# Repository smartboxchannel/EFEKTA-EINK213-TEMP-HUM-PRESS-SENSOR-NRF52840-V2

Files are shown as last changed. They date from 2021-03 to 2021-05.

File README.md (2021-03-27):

# EFEKTA-EINK213-TEMP-HUM-PRESS-SENSOR-NRF52
Micro weather station. Wireless temperature, humidity, pressure, weather forecast and light sensor. Designed on the nRF52840 wireless radio module. The temperature, humidity and pressure sensor BME280, SHT20, SHT21, SI7020, SI7021, HTU20D, HTU21D is used. Light sensor MAX44009. The device is powered by a CR2450 battery. Power consumption when transmitting data is 8mA, in sleep mode is 4.7uA.

#### GDEH0213B72 (GDEH0213B73, Waveshare V2): https://ali.ski/05GbQ

(250x122,2.13inch E-Ink raw display panel Without PCB Communicate via SPI interface)

#### MS88SF3: https://ali.ski/I_UNg

(New FCC CE RoHs Certificated Compact (18.5×12.5×2mm) and Flexible ultra-low power wireless BLE 5.0 Module based on nRF52840 SoCs)

#### Don't donate to me, it doesn't work in this world: https://paypal.me/efektalab , just buy

#### Sale: https://www.tindie.com/products/diyberk/multisensor-with-an-e-ink-display-213-inch/

Video: https://youtu.be/EHj37hnhy64

More info at http://efektalab.com/eink213

---

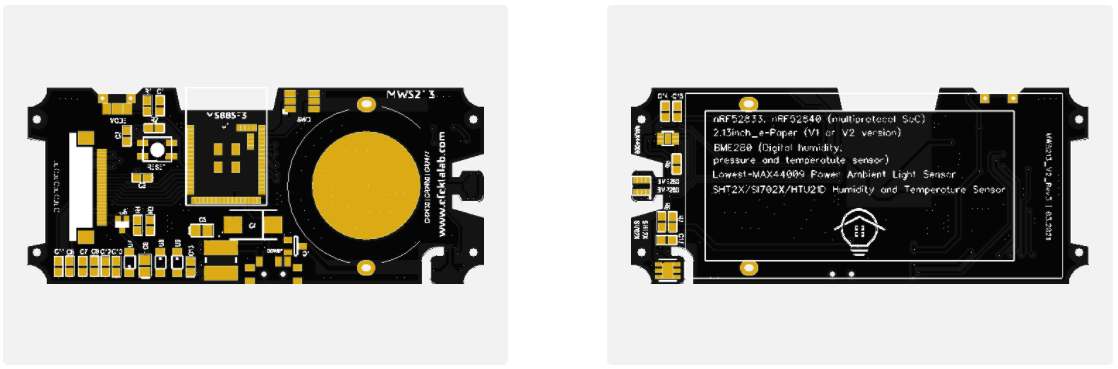
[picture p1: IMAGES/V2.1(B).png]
 

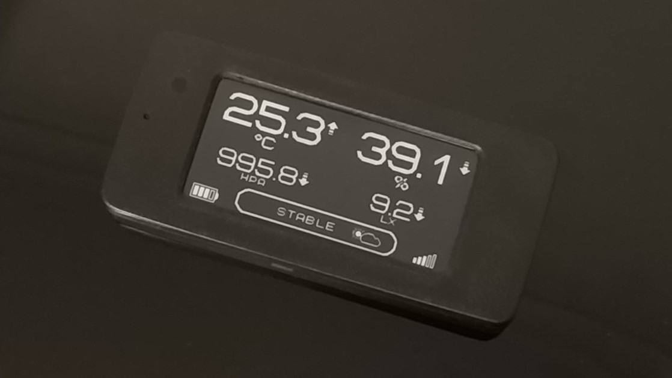
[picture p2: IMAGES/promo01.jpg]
 

---

---

### Instruction

#### First of all, I recommend installing the Arduino IDE portable (optional, but desirable)

https://www.arduino.cc/en/Guide/PortableIDE

#### 1. Install the latest arduino-nRF5 library (https://github.com/sandeepmistry/arduino-nRF5)

#### 2. Install the latest version of the MySensors library (https://github.com/mysensors/MySensors)

#### 3. Download the archive of this project to your computer

#### 4. Add support for devices of this project to the arduino-nRF5 library, the description is in the README.md file (https://github.com/smartboxchannel/EFEKTA-EINK213-TEMP-HUM-PRESS-SENSOR-NRF52840-V2/tree/master/for_sandeepmistry_nRF5/README.md)

#### 5. Add support for interrupts via gpiote, for this go to the ... packages \ sandeepmistry \ hardware \ nRF5 \ 0.7.0 \ cores \ nRF5 folder, and in the WInterrupts.c file, before the void GPIOTE_IRQHandler () function, add the line: \_\_attribute\_\_ ((weak ))

#### 6. Add the libraries in the archive () https://github.com/smartboxchannel/EFEKTA-EINK213-TEMP-HUM-PRESS-SENSOR-NRF52840-V2/tree/master/CODE/Arduino/libraries  of this project to the libraries folder on your computer ( path: ...\Documents\Arduino\libraries )

#### 7. Create an EINK213ED2 folder on your computer under the Arduino directory (Documents \ Arduino). Add the files of this project located in the Arduino section (https://github.com/smartboxchannel/EFEKTA-EINK213-TEMP-HUM-PRESS-SENSOR-NRF52840-V2/tree/master/CODE/Arduino) to the created EINK213ED2 folder

#### 8. Open the EINK213ED2.ino file in the Arduino IDE program, go to the aConfig.h tab and configure according to your board version and settings of your MySensors network.

#### 9. In the main menu of the Arduino IDE go to Tools-> Boards-> Nordic Semiconductors nRF5 Boards, in the list that opens, select the EFEKTA MWS213 V2 nRF52840 board. In the menu of the selected board, select the type of clock crystal (external), also select the Reset: Enable item.

#### 10. Click on the icon - check and then download

---

---

## Components (BOM):

MINEW MS88SF3 FCC CE RoHs Certificated wireless module nRF52840 SoCs - https://ali.ski/9LnWZ (1 pc - $7.75)

MAX44009EDT  - https://ali.ski/_PLrJ  (5 pcs - $9.3)
OR
MAX44009EDT  - https://ali.ski/bZoMnn  (1 pc - $1.9)

BME280 - https://ali.ski/wLEIir (2 pcs - $11.5)

Waveshare 250x122 2,13 - https://ali.ski/D4eOVU (1pc - $12.3)

FPC FFC 0.5mm connector socket 24 pin - https://ali.ski/lCBot0 (1 p - $0.77)

Cell Holder CR2450 - https://ali.ski/gMd2Y (10 pcs - $2)

Micro Screws M1.4 3mm - https://ali.ski/gaFdO (100 pcs - $1)

Micro Screws M1.4 5mm - https://ali.ski/gaFdO (100 pcs - $1)

Micro SMD Tact Switch 2x4 2*4*3.5 - https://ali.ski/_D78Q (10 pcs - $1)

Neodymium magnet 15x3x3m - https://ali.ski/44p3R (10 pcs - $7)

Tantalum Capacitor 100UF 10V - https://ali.ski/Lx9iQd (10 pcs - $1,85)

Inductor Power Shielded Wirewound NR5040 5x5x4mm - https://ali.ski/iblu8q (50 pcs - $3)

Micro Button Tact Switch SMD 4Pin 3X4X2.5 - https://ali.ski/sGwFu (100 pcs - $1.7)

SMD Mini Toggle Slide Switch 7-Pin On/Off - https://ali.ski/xz9Yt (100 pcs - $3.2)

SI1308EDL - https://ali.ski/Q6Y12 (20 pcs - $5.3)
OR
Si1304BDL - https://ali.ski/938Klh (100 pcs - $15.5)

SMD Chip Multilayer Ceramic Capacitor 0603 1UF 25V - https://ali.ski/p3yr60 (100 pcs - $1.5)

SMD Chip Multilayer Ceramic Capacitor 0603 0.1UF 50V - https://ali.ski/p3yr60 (100 pcs - $1.5)

SMD Chip Multilayer Ceramic Capacitor 0805 4.7UF - https://ali.ski/iFXAc (100 pcs - $1.85)

MBR0530T1G - https://ali.ski/SJM7aK (100 pcs - $1.1)

SMD LED 0805 - https://ali.ski/wb6ZP (100 pcs - $2)

1% SMD resistor 0.47R 0603 - https://ali.ski/bX9HUg (100 pcs - $1.2)

1% SMD Resistor Kit Assorted Kit 1R-1M 0603 -  https://ali.ski/npItF (660 pcs - $1.45)

SUNLU PLA Carbon Fiber Premium 3D Printer Filament - https://ali.ski/bQkNR (1 pcs - $26.5)

405nm UV Resin For 3d Printer - https://ali.ski/sW0MUm (1 pcs - $18.5)

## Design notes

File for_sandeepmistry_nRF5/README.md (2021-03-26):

#### 1. Add lines from the file boards.txt to a file with the same name(boards.txt) located in the installed 'sandeepmistry' library. 

Path: ...\AppData\Local\Arduino15\packages\sandeepmistry\hardware\nRF5\0.7.0

#### 2. Replace the file platform.txt with a similar file from this repository 

Path: ...\AppData\Local\Arduino15\packages\sandeepmistry\hardware\nRF5\0.7.0

#### 3. Add the folder EFEKTA_MWS213_V2 with all the attached files to the \0.7.0 folder

Path: ...\AppData\Local\Arduino15\packages\sandeepmistry\hardware\nRF5\0.7.0\

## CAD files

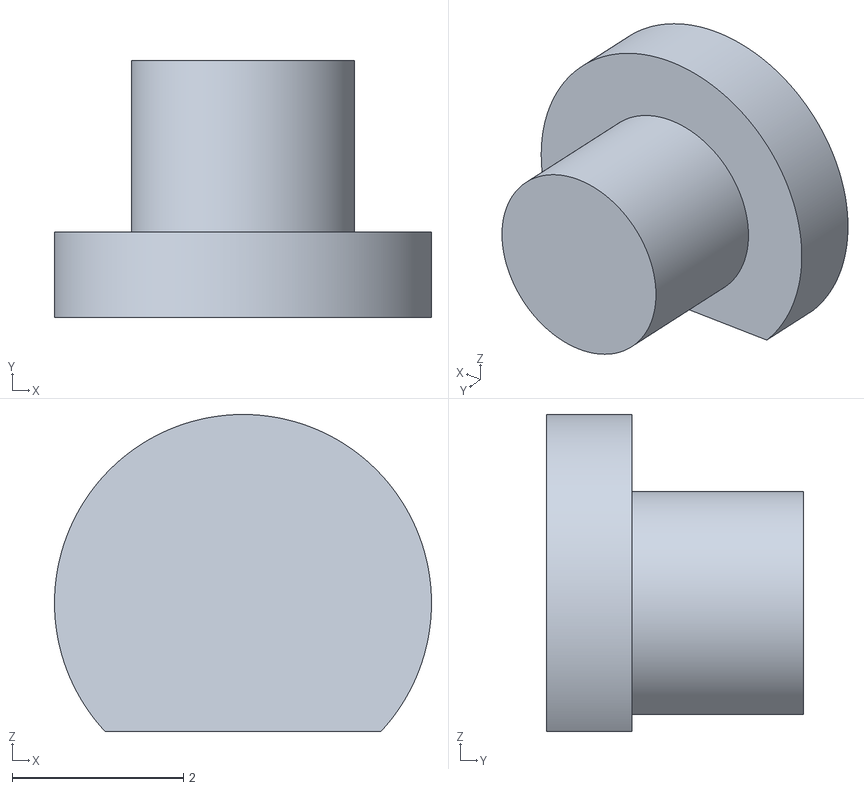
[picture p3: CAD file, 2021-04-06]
CASE/00003.STL
4.40 x 3.00 x 3.70

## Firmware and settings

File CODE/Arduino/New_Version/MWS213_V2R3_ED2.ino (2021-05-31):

#include "aConfig.h"
#include <Wire.h>
#include <SPI.h>
#include "eink213_V2.h"
#include "imagedata.h"
#include "einkpaint.h"
unsigned char image[4000];
Paint paint(image, 0, 0);
Epd epd;

#ifdef BME280INSTALLED
#include <Adafruit_Sensor.h>
#include <Adafruit_BME280.h>
#define SEALEVELPRESSURE_HPA (1013.25)
Adafruit_BME280 bosch;
#else
#include <Adafruit_BMP280.h>
Adafruit_BMP280 bosch;
#include "Adafruit_HTU21DF.h"
Adafruit_HTU21DF sensor = Adafruit_HTU21DF();
#endif

#ifdef LIGHTSENS
#include <MAX44009.h>
MAX44009 light;
#endif


float last_tmp;
bool upTemp;
bool downTemp;

float last_hm;
bool upHum;
bool downHum;

float last_pr;
bool upPress;
bool downPress;

long last_l;
bool upLx;
bool downLx;


bool mesColorSet;
#ifdef SEND_RESET_REASON
bool mesReset;
#endif
bool mesBatSet;
bool mesVolt;
bool mesLink;
#ifdef LIGHTSENS
bool mesLight;
#endif
bool mesForec;
bool mesBaro;
bool mesHum;
bool mesTemp;
bool mesInfo;
bool needPresent;
bool metric;
bool colorPrint;
bool opposite_colorPrint;
bool sendAfterResTask;
bool changeB = true;
bool changeC = true;
bool updateink1;
bool updateink2;
bool updateink3;
bool updateink4;
bool updateinkclear;
bool check;
bool chek_h = true;
bool flag_update_transport_param;
bool flag_sendRoute_parent;
bool flag_no_present;
bool flag_nogateway_mode;
bool flag_find_parent_process;
bool nosleep;
bool change;
bool Ack_FP;
bool tch;
bool hch;
bool bch;
bool vch;
bool pch;
bool fch;
#ifdef LIGHTSENS
bool lch;
#endif
bool configMode;
bool button_flag;
uint8_t lang;
uint8_t cpNom;
uint8_t cpCount;
uint8_t battSend;
uint8_t timeSend = 1;
uint8_t battery;
uint8_t old_battery;
uint8_t err_delivery_beat;
const uint16_t shortWait = 10;
int16_t temperatureInt;
int16_t humidityInt;
int16_t pressureInt;
int16_t pressure_mmInt;
uint16_t batteryVoltage;
uint16_t old_batteryVoltage;
uint16_t minuteT = 60000;
uint16_t BATT_TIME;
uint16_t BATT_COUNT;
int16_t nRFRSSI;
int16_t old_nRFRSSI = 127;
int16_t myid;
int16_t mypar;
int16_t old_mypar = -1;
float temperatureSend;
float pressureSend;
float humiditySend;
float old_temperature;
float old_humidity;
float old_pressure;
float tempThreshold = 0.5; // порог сравнения в предыдущими показаниями температуры
float humThreshold = 2.5; // порог сравнения в предыдущими показаниями влажности
float pressThreshold = 1.0; // порог сравнения в предыдущими показаниями влажности
float batteryVoltageF;


#ifdef LIGHTSENS
float brightness;
float old_brightness;
float brightThreshold = 10.0;
#endif

uint32_t configMillis;
uint32_t previousMillis;
uint32_t SLEEP_TIME;
uint32_t stopTimer;
uint32_t startTimer;
uint32_t PRECISION_TIME_WDT;
const uint32_t SLEEP_TIME_WDT = 10000;
uint32_t sleepTimeCount;


int16_t mtwr;
#define MY_TRANSPORT_WAIT_READY_MS (mtwr)
#include <MySensors.h>
#define TEMP_CHILD_ID 0
#define HUM_CHILD_ID 1
#define BARO_CHILD_ID 2
#define FORECAST_CHILD_ID 3
#ifdef LIGHTSENS
#define LUX_SENS_CHILD_ID 4
#endif
#define SIGNAL_Q_ID 100
#define BATTERY_VOLTAGE_ID 101
#define SET_BATT_SEND_ID 103
#define SET_COLOR_ID 104
#ifdef SEND_RESET_REASON
#define RESET_REASON_ID 105
#endif

MyMessage sqMsg(SIGNAL_Q_ID, V_VAR1);
MyMessage bvMsg(BATTERY_VOLTAGE_ID, V_VAR1);



// ##############################################################################################################
// #                                                 FORECAST                                                   #
// ##############################################################################################################
#define CONVERSION_FACTOR (1.0/10.0)         // used by forecast algorithm to convert from Pa to kPa, by dividing hPa by 10.
const char *weather[] = { "stable", "sunny", "cloudy", "unstable", "thunderstorm", "unknown" };
enum FORECAST
{
  STABLE = 0,                     // "Stable Weather Pattern"
  SUNNY = 1,                      // "Slowly rising Good Weather", "Clear/Sunny "
  CLOUDY = 2,                     // "Slowly falling L-Pressure ", "Cloudy/Rain "
  UNSTABLE = 3,                   // "Quickly rising H-Press",     "Not Stable"
  THUNDERSTORM = 4,               // "Quickly falling L-Press",    "Thunderstorm"
  UNKNOWN = 5                     // "Unknown (More Time needed)
};
int16_t forecast;
int16_t  old_forecast = -1;            // Stores the previous forecast, so it can be compared with a new forecast.
const int LAST_SAMPLES_COUNT = 5;
float lastPressureSamples[LAST_SAMPLES_COUNT];
int minuteCount = 0;              // Helps the forecst algorithm keep time.
bool firstRound = true;           // Helps the forecast algorithm recognise if the sensor has just been powered up.
float pressureAvg;                // Average value is used in forecast algorithm.
float pressureAvg2;               // Average after 2 hours is used as reference value for the next iteration.
float dP_dt;                      // Pressure delta over time


// SDK PORT
uint32_t PIN_BUTTON_MASK;
volatile byte buttIntStatus = 0;
#define APP_GPIOTE_MAX_USERS 1
extern "C" {
#include "app_gpiote.h"
#include "nrf_gpio.h"
}
static app_gpiote_user_id_t m_gpiote_user_id;



void preHwInit() {
  pinMode(PIN_BUTTON, INPUT);
  pinMode(20, INPUT);
}

void before() {

  // ########################################## CONFIG MCU ###############################################

  NRF_POWER->DCDCEN = 1;
  NRF_SAADC ->ENABLE = 0;
  NRF_PWM0  ->ENABLE = 0;

  NRF_NFCT->TASKS_DISABLE = 1;
  NRF_NVMC->CONFIG = 1;
  NRF_UICR->NFCPINS = 0;
  NRF_NVMC->CONFIG = 0;
  NRF_PWM1  ->ENABLE = 0;
  NRF_PWM2  ->ENABLE = 0;
  NRF_TWIM1 ->ENABLE = 0;
  NRF_TWIS1 ->ENABLE = 0;
  NRF_RADIO->TXPOWER = 0x8UL;

#ifndef MY_DEBUG
  NRF_UART0->ENABLE = 0;
#endif

  //########################################## INIT HAPPY ##############################################

  happy_init();


  //########################################## CONFIG PROG ###############################################

  battSend = loadState(103);  // Saving in memory the interval of sending data about battery charge and signal quality,
  // maximized 24 hours, if 0, the sending does not do, only updates the info on the screen
  if (battSend > 24) {
    battSend = 6;
    saveState(103, battSend);
  }
  //battSend = 1; // for the test, 1 hour

  if (loadState(104) > 1) {
    saveState(104, 0);
  }
  colorChange(loadState(104));
  //colorChange(true); // для теста, true или false

  timeConf();

  delay(1000);

  //########################################## EINK INIT ###############################################

  displayStart();
}


void presentation()
{
  if (needPresent == true) {
    if (flag_nogateway_mode == false) {
      if (mesInfo == false) {
        check = sendSketchInfo(SN, SV);
        if (!check) {
          wait(shortWait * 10);
          _transportSM.failedUplinkTransmissions = 0;
        }
      }
      if (check) {
        mesInfo = true;
      }

      if (mesTemp == false) {
        check = present(TEMP_CHILD_ID, S_TEMP, "TEMPERATURE");
        if (!check) {
          needPresent = true;
          wait(shortWait * 10);
          _transportSM.failedUplinkTransmissions = 0;
        } else {
          mesTemp = true;
          //needPresent = false;
        }
      }

      if (mesHum == false) {
        check = present(HUM_CHILD_ID, S_HUM, "HUMIDITY");
        if (!check) {
          needPresent = true;
          wait(shortWait * 10);
          _transportSM.failedUplinkTransmissions = 0;
        } else {
          mesHum = true;
          //needPresent = false;
        }
      }

      if (mesBaro == false) {
        check = present(BARO_CHILD_ID, S_BARO, "PRESSURE");
        if (!check) {
          needPresent = true;
          wait(shortWait * 10);
          _transportSM.failedUplinkTransmissions = 0;
        } else {
          mesBaro = true;
          //needPresent = false;
        }
      }

      if (mesForec == false) {
        check = present(FORECAST_CHILD_ID, S_CUSTOM, "FORECAST");
        if (!check) {
          needPresent = true;
          wait(shortWait * 10);
          _transportSM.failedUplinkTransmissions = 0;
        } else {
          mesForec = true;
          //needPresent = false;
        }
      }

#ifdef LIGHTSENS
      if (mesLight == false) {
        check = present(LUX_SENS_CHILD_ID, S_LIGHT_LEVEL, "LUX");
        if (!check) {
          needPresent = true;
          wait(shortWait * 10);
          _transportSM.failedUplinkTransmissions = 0;
        } else {
          mesLight = true;
          //needPresent = false;
        }
      }
#endif

      if (mesLink == false) {
        check = present(SIGNAL_Q_ID, S_CUSTOM, "SIGNAL %");
        if (!check) {
          needPresent = true;
          wait(shortWait * 10);
          _transportSM.failedUplinkTransmissions = 0;
        } else {
          mesLink = true;
          //needPresent = false;
        }
      }

      if (mesVolt == false) {
        check = present(BATTERY_VOLTAGE_ID, S_CUSTOM, "BATTERY VOLTAGE");
        if (!check) {
          needPresent = true;
          wait(shortWait * 10);
          _transportSM.failedUplinkTransmissions = 0;
        } else {
          mesVolt = true;
          //needPresent = false;
        }
      }

      if (mesBatSet == false) {
        check = present(SET_BATT_SEND_ID, S_CUSTOM, "BATT SEND INTERTVAL | H");
        if (!check) {
          needPresent = true;
          wait(shortWait * 10);
          _transportSM.failedUplinkTransmissions = 0;
        } else {
          mesBatSet = true;
          //needPresent = false;
        }
      }

#ifdef SEND_RESET_REASON
      if (mesReset == false) {
        check = present(RESET_REASON_ID, S_CUSTOM, "RESTART REASON");
        if (!check) {
          needPresent = true;
          wait(shortWait * 10);
          _transportSM.failedUplinkTransmissions = 0;
        } else {
          mesReset = true;
          //needPresent = false;
        }
      }
#endif

      if (mesColorSet == false) {
        check = present(SET_COLOR_ID, S_CUSTOM, "COLOR W/B");
        if (!check) {
          needPresent = true;
          wait(shortWait * 10);
          _transportSM.failedUplinkTransmissions = 0;
        } else {
          mesColorSet = true;
          //needPresent = false;
        }
      }

      if (mesInfo == true && mesTemp == true && mesHum == true && mesBaro == true && mesForec == true && mesLink == true && mesVolt == true && mesBatSet == true && mesColorSet == true) {
        needPresent = false;
#ifdef LIGHTSENS
        if (mesLight == false) {
          needPresent = true;
        }
#endif
#ifdef SEND_RESET_REASON
        if (mesReset == false) {
          needPresent = true;
        }
#endif
      }
      wait(shortWait * 10);
      sendAfterResTask = true;
      configSend();
    }
  }
}

void rstPresent(void) {
  mesInfo = false;
  mesTemp = false;
  mesHum = false;
  mesBaro = false;
  mesForec = false;
#ifdef LIGHTSENS
  mesLight = false;
#endif
  mesLink = false;
  mesVolt = false;
  mesBatSet = false;
#ifdef SEND_RESET_REASON
  mesReset = false;
#endif
  mesColorSet = false;
}


void setup()
{
  config_Happy_node();
  CORE_DEBUG(PSTR("MyS: CONFIG HAPPY NODE\n"));
  if (flag_nogateway_mode == false) {
    epd.Init(PART);
    epd.Clear(colorPrint, PART);
    paint.Clear(opposite_colorPrint);
#ifdef LANG_RU
    DrawImageWH(&paint, 42, 71, IMAGE_CON, 48, 108, colorPrint);
    DrawImageWH(&paint, 85, 71, IMAGE_CONACTIV, 16, 108, colorPrint);
#else
    DrawImageWH(&paint, 42, 71, IMAGE_ENCON, 48, 108, colorPrint);
    DrawImageWH(&paint, 85, 71, IMAGE_ECONACTIV, 16, 108, colorPrint);
#endif
    epd.DisplayPart(paint.GetImage());
    epd.Sleep();
    sendResetReason();
  } else {
    epd.Init(PART);
    epd.Clear(colorPrint, PART);
    paint.Clear(opposite_colorPrint);
#ifdef LANG_RU
    DrawImageWH(&paint, 42, 71, IMAGE_CON, 48, 108, colorPrint);
    DrawImageWH(&paint, 85, 71, IMAGE_NOCONACTIV, 16, 108, colorPrint);
#else
    DrawImageWH(&paint, 42, 71, IMAGE_ENCON, 48, 108, colorPrint);
    DrawImageWH(&paint, 85, 71, IMAGE_ENOCONACTIV, 16, 108, colorPrint);
#endif
    epd.DisplayPart(paint.GetImage());
    epd.Sleep();
  }

  CORE_DEBUG(PSTR("MyS: SEND CONFIG PARAMETERS\n"));
  sendAfterResTask = true;
  sleepTimeCount = SLEEP_TIME;
  metric = getControllerConfig().isMetric;
  transportDisable();
  wait(10);
  thpSensorInit();
  wait(50);
#ifdef LIGHTSENS
  light.begin();
  wait(50);
#endif
  interrupt_Init();
  wait(20);
  readBatt();
  startTimer = millis();
}



void loop() {
  if (flag_update_transport_param == true) {
    update_Happy_transport();
  }
  if (flag_sendRoute_parent == true) {
    present_only_parent();
  }
  if (isTransportReady() == true) {
    if (flag_find_parent_process == true) {
      find_parent_process();
    }
    if (flag_nogateway_mode == false) {


      if (configMode == false) {
        if (buttIntStatus == PIN_BUTTON) {
          if (digitalRead(PIN_BUTTON) == 0 && button_flag == false) {
            button_flag = true;
            previousMillis = millis();
          }

          if (digitalRead(PIN_BUTTON) == 0 && button_flag == true) {
            if ((millis() - previousMillis > 0) && (millis() - previousMillis <= 3000)) {
              if (updateink1 == false) {
                einkZeropush();
                updateink1 = true;
              }

            }
            if ((millis() - previousMillis > 3000) && (millis() - previousMillis <= 4000)) {
              if (updateinkclear == false) {
                epd.Clear(colorPrint, PART);
                updateinkclear = true;
              }

            }
            if ((millis() - previousMillis > 4000) && (millis() - previousMillis <= 7000)) {
              if (updateink2 == false) {
                einkOnepush();
                updateink2 = true;
                updateinkclear = false;
              }
            }
            if ((millis() - previousMillis > 7000) && (millis() - previousMillis <= 8000)) {
              if (updateinkclear == false) {
                epd.Clear(colorPrint, PART);
                updateinkclear = true;
              }

            }
            if ((millis() - previousMillis > 8000) && (millis() - previousMillis <= 11000)) {
              if (updateink3 == false) {
                einkOnePluspush();
                updateink3 = true;
                updateinkclear = false;
              }
            }
            if ((millis() - previousMillis > 11000) && (millis() - previousMillis <= 12000)) {
              if (updateinkclear == false) {
                epd.Clear(colorPrint, PART);
                updateinkclear = true;
              }

            }
            if ((millis() - previousMillis > 12000) && (millis() - previousMillis <= 15000)) {
              if (updateink4 == false) {
                einkTwopush();
                updateink4 = true;
                updateinkclear = false;
              }
            }
            if (millis() - previousMillis > 15000) {
              if (updateinkclear == false) {
                epd.Clear(colorPrint, PART);
                updateinkclear = true;
                buttIntStatus = 0;
                change = true;
                sleepTimeCount = SLEEP_TIME;
              }

            }
          }

          if (digitalRead(PIN_BUTTON) == 1 && button_flag == 1) {
            if (millis() - previousMillis <= 3000 && button_flag == 1)
            {
              einkPushEnd();
              reseteinkset();
              if (colorPrint == true) {
                colorPrint = false;
                colorChange(colorPrint);
              } else {
                colorPrint = true;
                colorChange(colorPrint);
              }
              sleepTimeCount = 0;
              readSensor();
              change = false;
              sendData();
              wait(20);
              eInkUpdate();
              change = false;
              button_flag = false;
              buttIntStatus = 0;
              nosleep = false;
            }
            if ((millis() - previousMillis > 4000) && (millis() - previousMillis <= 7000) && button_flag == 1)
            {
              einkPushEnd();
              reseteinkset();
              transportReInitialise();
              wait(shortWait);
              rstPresent();
              presentation();
              transportDisable();
              wait(shortWait);
              sleepTimeCount = 0;
              readSensor();
              change = false;
              sendData();
              wait(20);
              eInkUpdate();
              change = false;
              button_flag = false;
              buttIntStatus = 0;
              nosleep = false;
            }
            if ((millis() - previousMillis > 8000) && (millis() - previousMillis <= 11000) && button_flag == 1)
            {
              einkPushEnd();
              reseteinkset();
              configMode = true;
              button_flag = false;
              buttIntStatus = 0;
              transportReInitialise();
              wait(shortWait);
              NRF5_ESB_startListening();
              wait(shortWait * 5);
              configMillis = millis();
            }
            if ((millis() - previousMillis > 12000) && (millis() - previousMillis <= 15000) && button_flag == 1)
            {
              einkPushEnd();
              wait(1500);
              new_device();
            }
            if (((millis() - previousMillis > 3000) && (millis() - previousMillis <= 4000) && button_flag == true) || ((millis() - previousMillis > 7000) && (millis() - previousMillis <= 8000) && button_flag == true) || ((millis() - previousMillis > 11000) && (millis() - previousMillis <= 12000) && button_flag == true) || ((millis() - previousMillis > 15000) && button_flag == true))
            {
              wdt_nrfReset();
              reseteinkset();
              sleepTimeCount = 0;
              readSensor();
              change = false;
              sendData();
              wait(20);
              eInkUpdate();
              change = false;
              button_flag = false;
              buttIntStatus = 0;
              nosleep = false;
            }
          }
        } else {
          sleepTimeCount++;
          if (sleepTimeCount >= SLEEP_TIME) {
            sleepTimeCount = 0;
            readSensor();
            if (change == true) {
              sendData();
              wait(100);
              eInkUpdate();
              change = false;
            }
          }
          nosleep = false;
        }
      } else {
        if (millis() - configMillis > 20000) {
          transportDisable(); // вроде потому что один фиг сразу в сон? ....не все таки раскоментить потому что сон не сразу а сначала обновление экрана
          configMode = false;
          sleepTimeCount = 0;
          readSensor();
          change = false;
          sendData();
          wait(20);
          eInkUpdate();
          change = false;
          button_flag = false;
          buttIntStatus = 0;
          nosleep = false;
        }
        wdt_nrfReset();
      }
    } else {
      if (buttIntStatus == PIN_BUTTON) {
        if (digitalRead(PIN_BUTTON) == 0 && button_flag == 0) {
          button_flag = 1;
          previousMillis = millis();
        }

        if (digitalRead(PIN_BUTTON) == 0 && button_flag == 1) {
          if ((millis() - previousMillis > 0) && (millis() - previousMillis <= 3000)) {
            if (updateink1 == false) {
              einkZeropush();
              updateink1 = true;
            }
          }
          if ((millis() - previousMillis > 3000) && (millis() - previousMillis <= 4000)) {
            if (updateinkclear == false) {
              epd.Clear(colorPrint, PART);
              updateinkclear = true;
            }
          }
          if ((millis() - previousMillis > 4000) && (millis() - previousMillis <= 7000)) {
            if (updateink2 == false) {
              einkOnepush();
              updateink2 = true;
              updateinkclear = false;
            }
          }
          if ((millis() - previousMillis > 7000) && (millis() - previousMillis <= 8000)) {
            if (updateinkclear == false) {
              epd.Clear(colorPrint, PART);
              updateinkclear = true;
            }
          }
          if ((millis() - previousMillis > 8000) && (millis() - previousMillis <= 11000)) {
            if (updateink4 == false) {
              einkTwopush();
              updateink4 = true;
              updateinkclear = false;
            }
          }
          if (millis() - previousMillis > 11000) {
            if (updateinkclear == false) {
              epd.Clear(colorPrint, PART);
              updateinkclear = true;
              buttIntStatus = 0;
              change = true;
              sleepTimeCount = SLEEP_TIME;
            }

          }
        }
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

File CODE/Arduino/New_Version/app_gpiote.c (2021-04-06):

// ########################################  Thermometer and hygrometer on nRF52840 #################################################### //
//                                                                                                                                       //
//                                                                                                                                       //
//                                                                                                                                       //
//                                                                                                                                       //
//                                                                                                                                       //
//                                                                                                                                       //
//                                                                                                                                       //
// ##################################################################################################################################### //

#include "app_gpiote.h"
#include <string.h>
//#include "app_util.h"
#include "nrf_gpio.h"


/**@brief GPIOTE user type. */
typedef struct
{
    uint32_t                   pins_mask;             /**< Mask defining which pins user wants to monitor. */
    uint32_t                   pins_low_to_high_mask; /**< Mask defining which pins will generate events to this user when toggling low->high. */
    uint32_t                   pins_high_to_low_mask; /**< Mask defining which pins will generate events to this user when toggling high->low. */
    uint32_t                   sense_high_pins;       /**< Mask defining which pins are configured to generate GPIOTE interrupt on transition to high level. */
    app_gpiote_event_handler_t event_handler;         /**< Pointer to function to be executed when an event occurs. */
} gpiote_user_t;


static uint32_t        m_enabled_users_mask;          /**< Mask for tracking which users are enabled. */
static uint8_t         m_user_array_size;             /**< Size of user array. */
static uint8_t         m_user_count;                  /**< Number of registered users. */
static gpiote_user_t * mp_users = NULL;               /**< Array of GPIOTE users. */


/**@brief Toggle sense level for specified pins.
 *
 * @param[in]   p_user   Pointer to user structure.
 * @param[in]   pins     Bitmask specifying for which pins the sense level is to be toggled.
 */
static void sense_level_toggle(gpiote_user_t * p_user, uint32_t pins)
{
    uint32_t pin_no;
    
    for (pin_no = 0; pin_no < NO_OF_PINS; pin_no++)
    {
        uint32_t pin_mask = (1 << pin_no);
        
        if ((pins & pin_mask) != 0)
        {
            uint32_t sense;

            // Invert sensing.
            if ((p_user->sense_high_pins & pin_mask) == 0)
            {
                sense = GPIO_PIN_CNF_SENSE_High << GPIO_PIN_CNF_SENSE_Pos;
                p_user->sense_high_pins |= pin_mask;
            }
            else
            {
                sense = GPIO_PIN_CNF_SENSE_Low << GPIO_PIN_CNF_SENSE_Pos;
                p_user->sense_high_pins &= ~pin_mask;
            }

            NRF_GPIO->PIN_CNF[pin_no] &= ~GPIO_PIN_CNF_SENSE_Msk;
            NRF_GPIO->PIN_CNF[pin_no] |= sense;
        }
    }
}


/**@brief GPIOTE interrupt handler.
 */
void GPIOTE_IRQHandler(void)
{
    uint8_t  i;
    uint32_t pins_state = NRF_GPIO->IN;
    
    // Clear event.
    NRF_GPIOTE->EVENTS_PORT = 0;
    
    // Check all users.
    for (i = 0; i < m_user_count; i++)
    {
        gpiote_user_t * p_user = &mp_users[i];

        // Check if user is enabled.
        if (((1 << i) & m_enabled_users_mask) != 0)
        {
            uint32_t transition_pins;
            uint32_t event_low_to_high;
            uint32_t event_high_to_low;

            // Find set of pins on which there has been a transition.
            transition_pins = (pins_state ^ ~p_user->sense_high_pins) & p_user->pins_mask;

            // Toggle SENSE level for all pins that have changed state.
            sense_level_toggle(p_user, transition_pins);
            
            // Call user event handler if an event has occurred.
            event_high_to_low = (~pins_state & p_user->pins_high_to_low_mask) & transition_pins;
            event_low_to_high = (pins_state & p_user->pins_low_to_high_mask) & transition_pins;

            if ((event_low_to_high | event_high_to_low) != 0)
            {
                p_user->event_handler(event_low_to_high, event_high_to_low);
            }
        }
    }
}
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

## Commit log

2021-02-12 gerber files
2021-05-31 V0.95
    Added information output to the screen without a light sensor
